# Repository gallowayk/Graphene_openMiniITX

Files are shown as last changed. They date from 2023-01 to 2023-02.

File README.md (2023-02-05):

# Graphene Open Air Mini-ITX Case - BETA

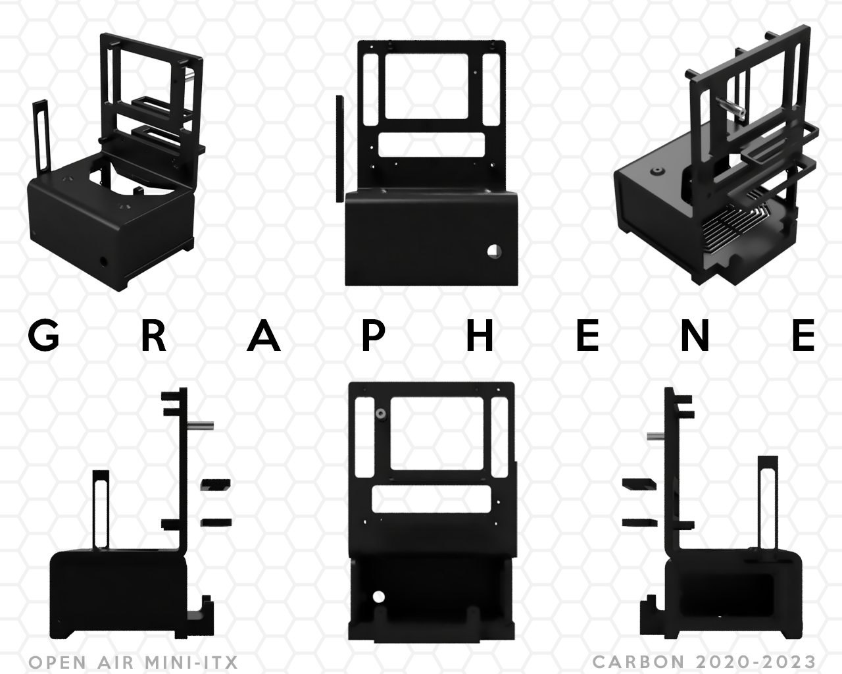
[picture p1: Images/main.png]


This repository contains files for an open-air mini-ITX case I've designed. There are some kinks to work out, but it should be most of the way there. 

Details:
- Fully 3D printable, only necessitating M3 screws and M3 heatset inserts
- SFX or SFX-L compatbility
- 240mm radiator support (open loop or AIO)
- Supports Mini-ITX motherboards (upright or rotated 90 degrees CCW)

Plans for future versions/variants:
- Official assembly guide
- mATX
- Fully support free
- Optimize space usage
- Space for system monitor display on front face
- Parameterize all dimensions

Suggested Print Settings:
- Infill:
  - PLA: 70-100% (due to proximity of heat sources)
  - ASA, ABS, Nylon: 40%
- Supports only neeed for PSU panel 
- Octet or Gyroid infill
- 4 Perimeters (walls)
- Orientation:
  - Upper:
    - Acceptable: Lying flat
    - Ideal: Print on side (warps easily and requires supports, but will be stronger)
  - Lower: 
    - Print on side with "Graphene" on build plate (printer needs to bridge decently)
  - Standoffs:
    - Print vertically
  - PSU panel
    - Lie flat on build plate, use 40% support density for a cleaner print
  - All other parts
    - Print with flattest side on bed

BOM (preliminary; subject to change)
- 6x M3x5mm(OD)x10mm(L) heatset inserts
- 12x M3x5mm(OD)x5mm(L) heatset inserts
- 18x M3x10mm socket head screws
- 2x M3x10mm button head socket cap screws
- 2x M3x5mm countersunk screw
- 4x 12mm(OD)x3mm(ID)x3mm(H) Magnets 
- 1x 16mm(OD) Momentary Switch (NO; normally open) 
- 1x Corsair PCIe 3.0 or 4.0 Riser Cable

Note:
This design and derivatives cannot, and should not, be sold, used for commercial purposes, etc. Individual use is absolutely fine and remixing is welcome.
.stls will be available right off the bat
.step files will be added once everything has been confirmed

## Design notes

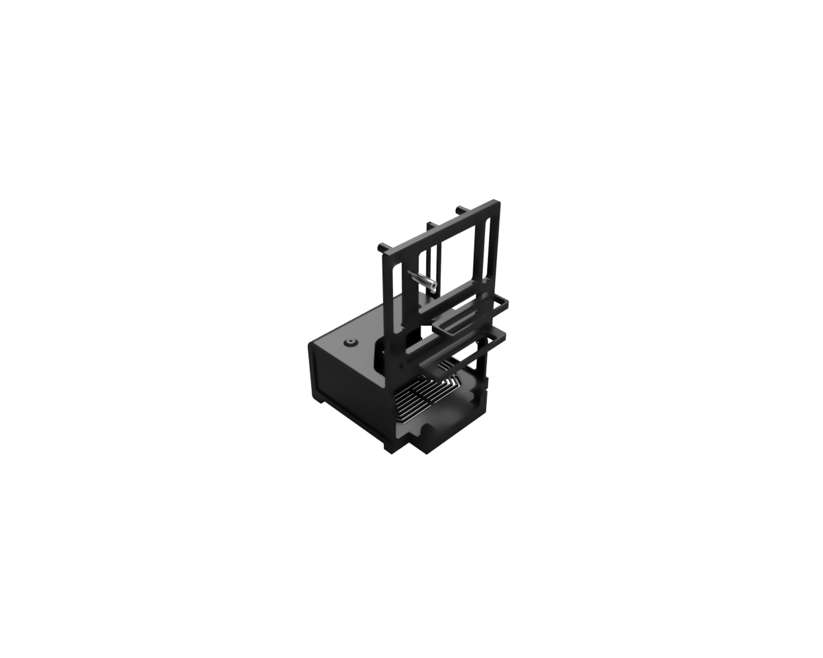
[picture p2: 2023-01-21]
Images/rearleft.png

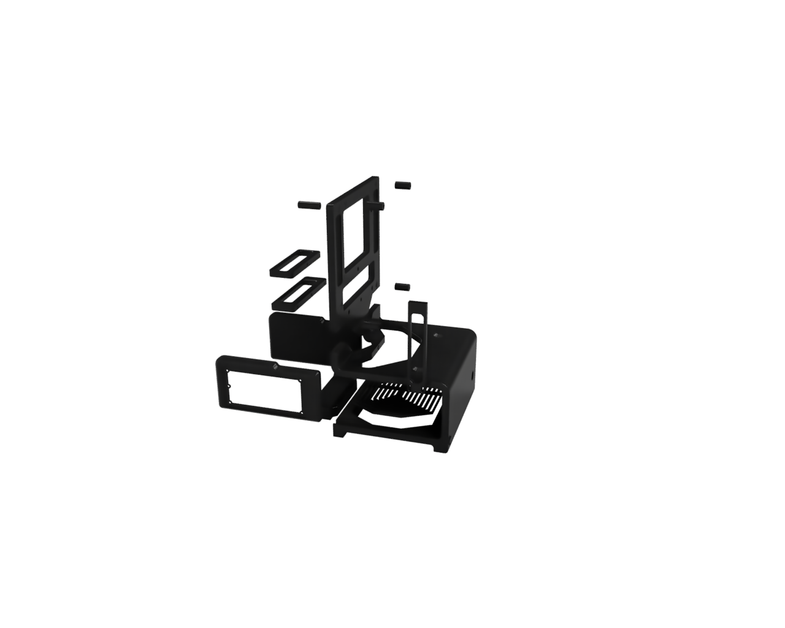
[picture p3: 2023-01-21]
Images/Exploded.png

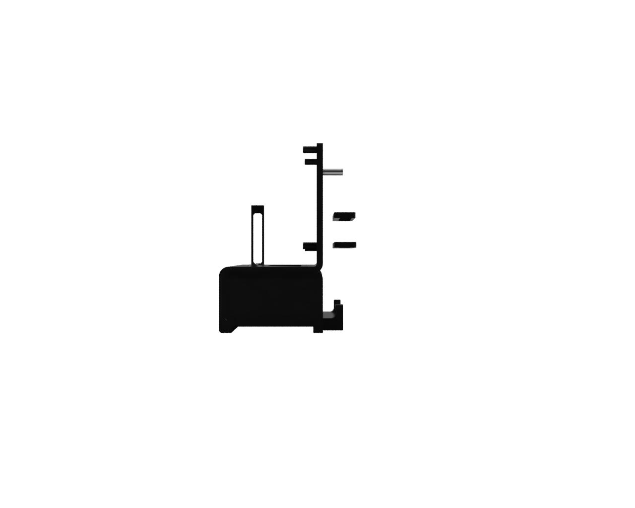
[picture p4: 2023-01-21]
Images/left.png

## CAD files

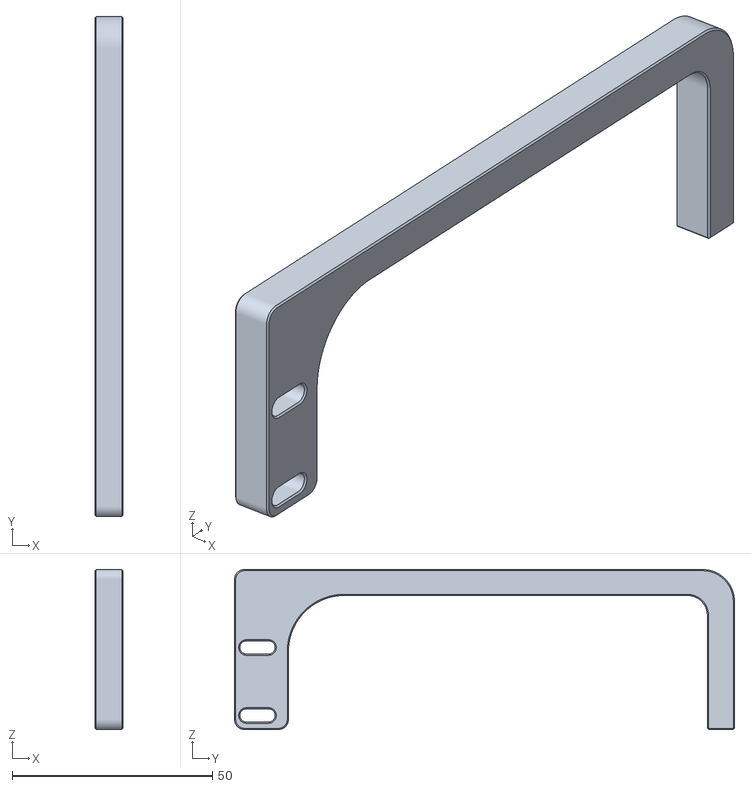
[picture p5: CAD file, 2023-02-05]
STLs/GPU_Support_New_x1.stl
7.00 x 125.0 x 40.0

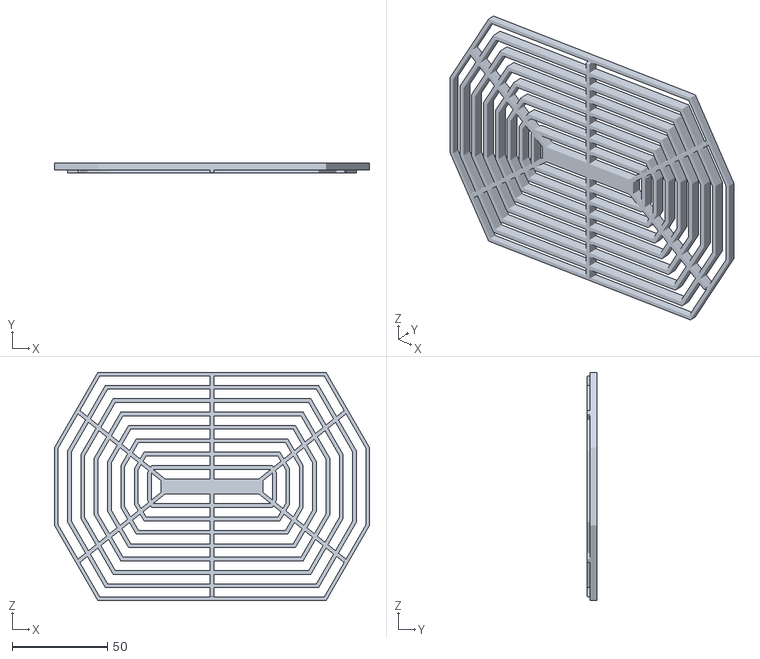
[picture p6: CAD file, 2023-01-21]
STLs/PSU_Grill_x1.stl
165.1 x 5.00 x 119.6

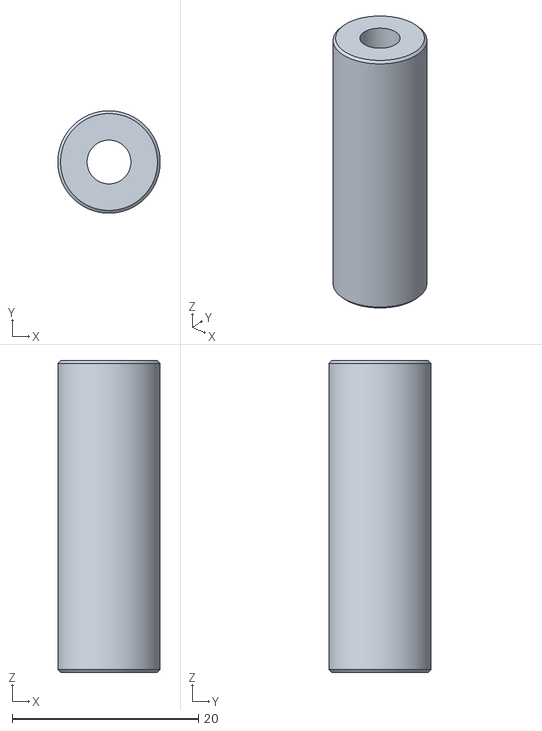
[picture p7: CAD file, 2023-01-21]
STLs/UpperRadStandoff_x1.stl
11.0 x 11.0 x 33.5

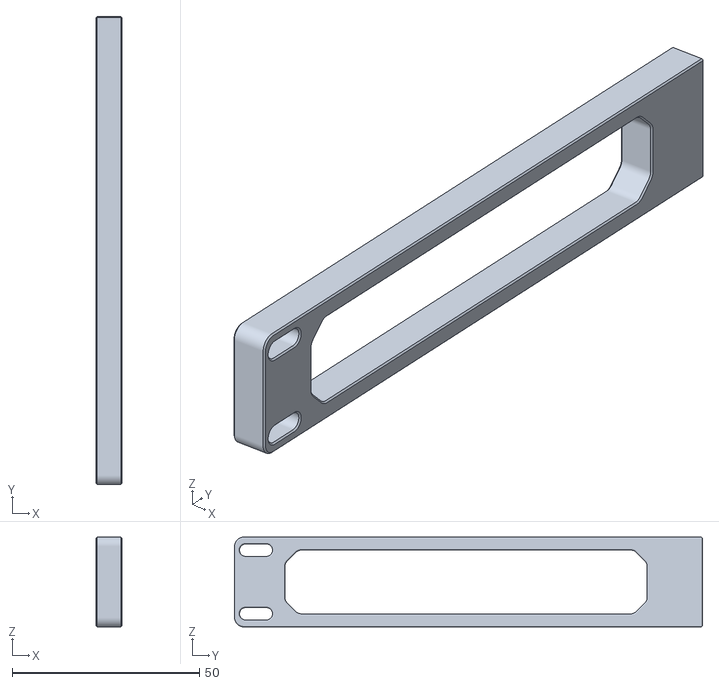
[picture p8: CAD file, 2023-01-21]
STLs/GPU_Support_x1.stl
7.00 x 125.0 x 24.0

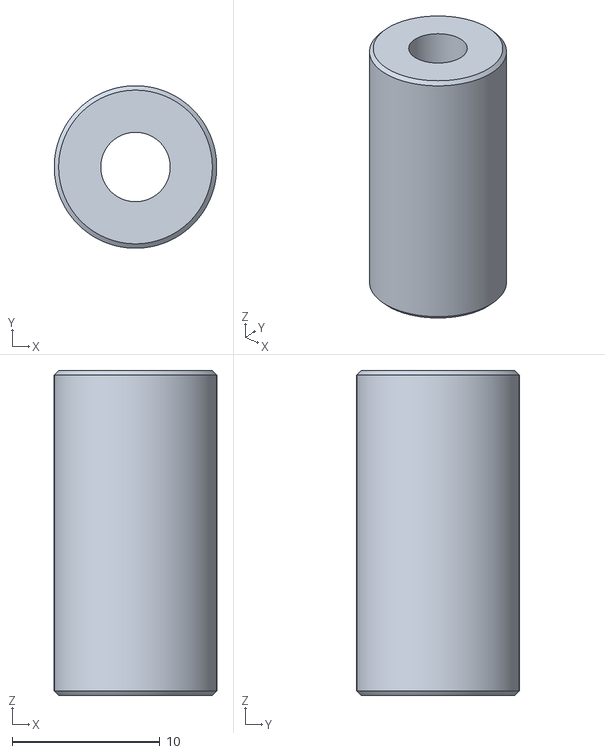
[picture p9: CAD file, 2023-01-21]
STLs/Standoff_x4.stl
11.0 x 11.0 x 22.0

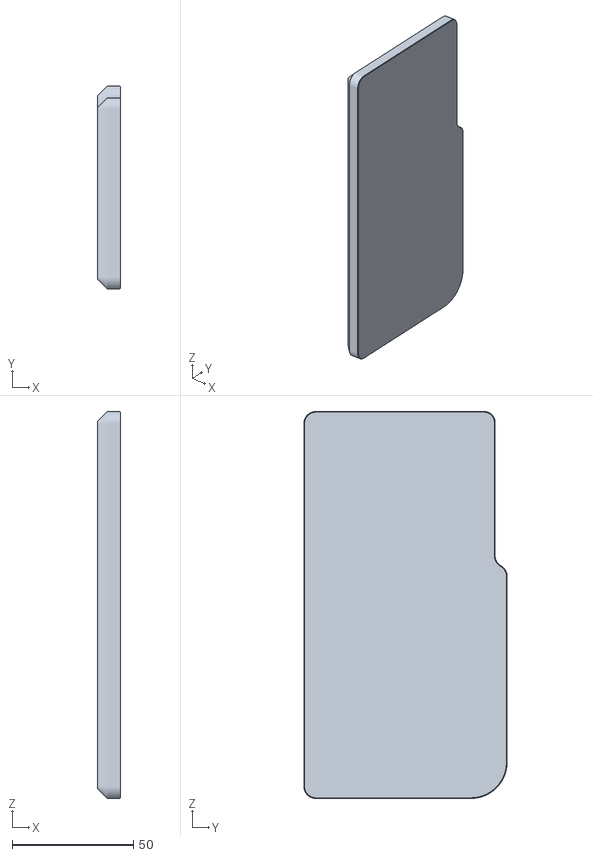
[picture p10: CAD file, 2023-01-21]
STLs/SolidSidePanel_x1.stl
9.50 x 84.0 x 159.9

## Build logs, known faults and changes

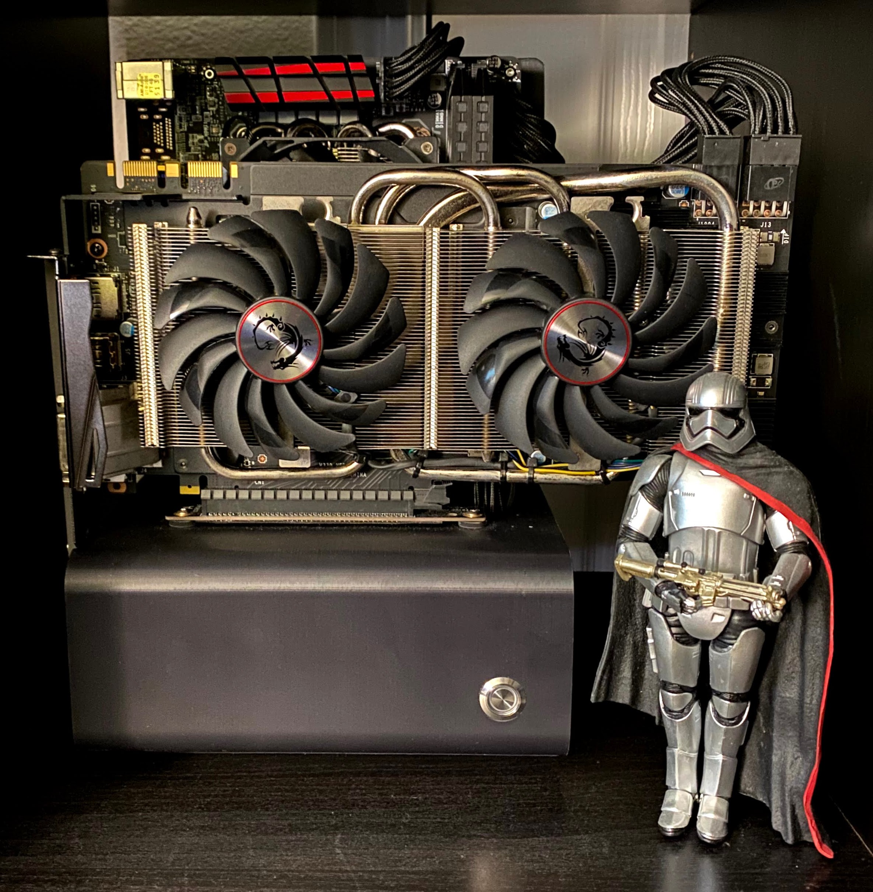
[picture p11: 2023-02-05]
History/v0.1_MSI_TwinFrozr.jpg

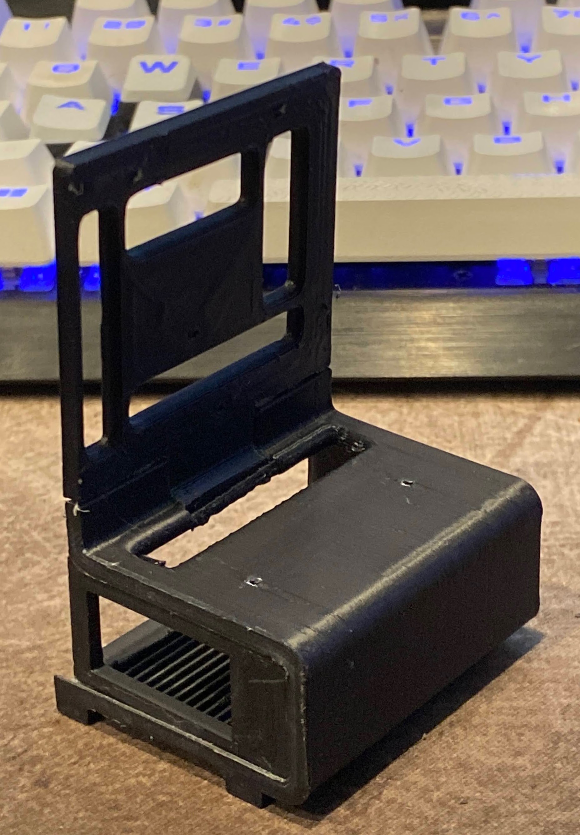
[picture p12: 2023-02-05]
History/v0_babyMockup.JPG

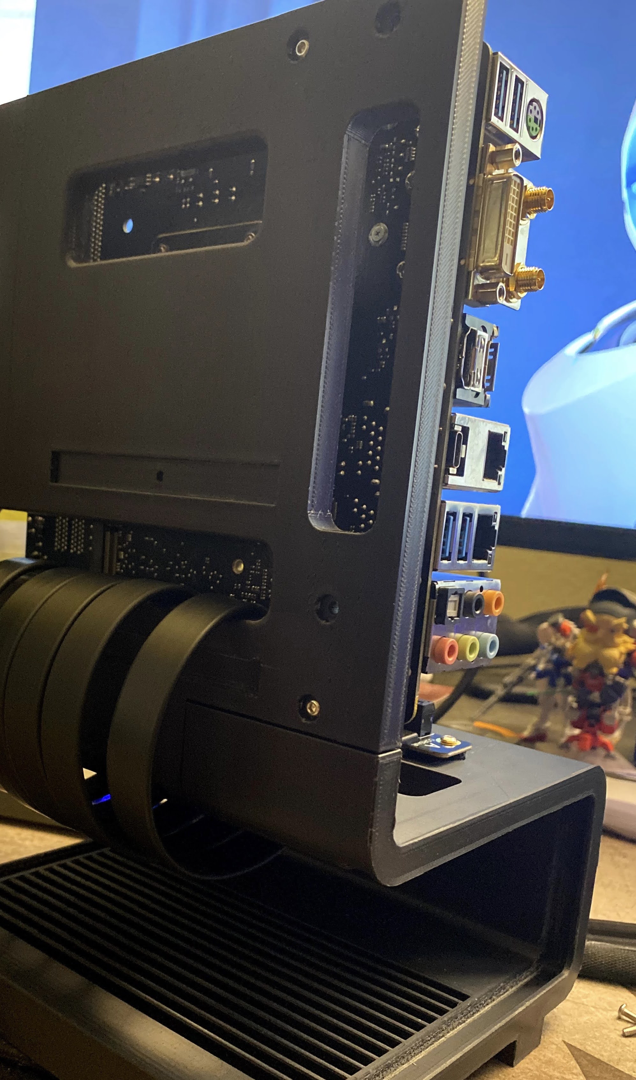
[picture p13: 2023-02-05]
History/v0_rear.JPG

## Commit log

2023-01-18 Initial STL Dump
    [CE5_Base_Large.3mf, CE5_Lower_OpenAir.3mf, Cable Managament - Small_v2.stl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]
2023-01-19 File Reset
    Revamped All Models
    [CE5_Base_Large.3mf, CE5_Lower_OpenAir.3mf, Cable Managament - Small_v2.stl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]
2023-01-21 Major Update
    Updated images and files.
    [GPU_Support_x1.stl, PSU_Grill_x1.stl, SolidSidePanel_x1.stl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]
2023-02-05 Updated/Added STLs
    "GPU_Support_New_x1" - Allows use of right angle adapters for the GPU. Should still provide ample rotational support.
    "SolidSidePanel_2.5inSSDCavity_x1" is an alternate solid side panel where you can mount a 2.5in SATA SSD. Mounting is friction fit.
    [GPU_Support_New_x1.stl]
